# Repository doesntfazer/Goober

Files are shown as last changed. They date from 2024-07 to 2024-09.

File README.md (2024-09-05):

## Goober
The Goober is a Hummingbird-like layout.

There are several different versions of the Goober layout.
For firmware Check out the [Keyboard Dweebs Firmware Repositore](https://github.com/doesntfazer/Keyboard-Dweebs-Firmware-repository)

## Goober Original


This keyboard is hot-swap, runs on rp2040 zero.
## Goobertrax


This keyboard is hot-swap, runs on rp2040 zero, and has a PMW3360 sensor trackball
## Goobertrax-e


This keyboard is hot-swap, runs on rp2040 zero, and has a PMW3360 sensor trackball. Additionally, it has 2 Panasonic rotary encoders, and 3 extra keys for mouse buttons
## CHore


This keyboard runs on FAK firmware, and is powered by a CH552G microcontroller.
## Goober CHOC


Same as original but with slightly different layout, and it is Choc Spaced.
## Goober-wi
No image available yet. Split wireless Goober.

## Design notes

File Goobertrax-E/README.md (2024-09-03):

# Goobertrax-E
# Project is sponsored by PCBWay!
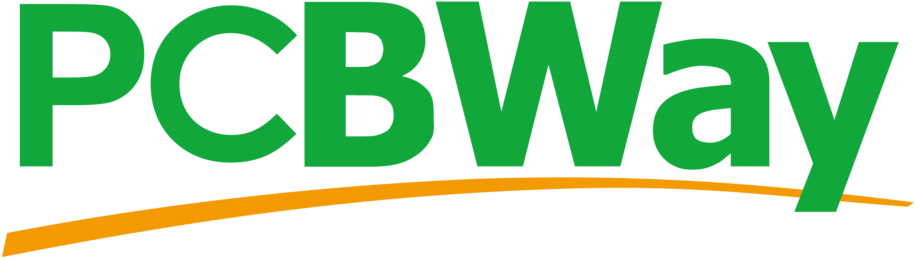
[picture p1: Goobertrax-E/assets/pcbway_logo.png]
PCBWay Logo


If you're not familiar with PCBWay, they're a fantastic company specializing in PCB prototyping and manufacturing. Whether you're a hobbyist or a professional, PCBWay offers high-quality PCB services at incredibly affordable prices. They offer a wide selection of colors and other options like full assembly!

I've been using PCBWay for my projects, and I can't recommend them enough. Their user-friendly interface makes it easy to upload your designs, and their fast turnaround times ensure you get your PCBs quickly, and you can finish your project on time. Plus, they offer a wide range of services, including PCB assembly, flexible PCBs, and even 3D printing and CNC!

Head on over to [PCBWay](https://pcbway.com/g/2afU7m) to get yourself a Goobertrax-E!

# About The Goobertrax-E
The Goobertrax-E is a 30 key hot swappable Hummingbird-like Keyboard using the RP2040 Zero for the MCU. Has a PMW3360 sensor Built into the PCB, 3 dedicated mouse keyb buttons, and supports 2 panisonic rotary encoders.

Keyboard is named the Goober because only a goober would use one. It is a very goofy keyboard. The thumbs keys are super "tucky" and it is awkward to figure out a layout. But once you get used to it, it just might become your favorite keyboard!

The keyboard runs on VIAL QMK firmware.
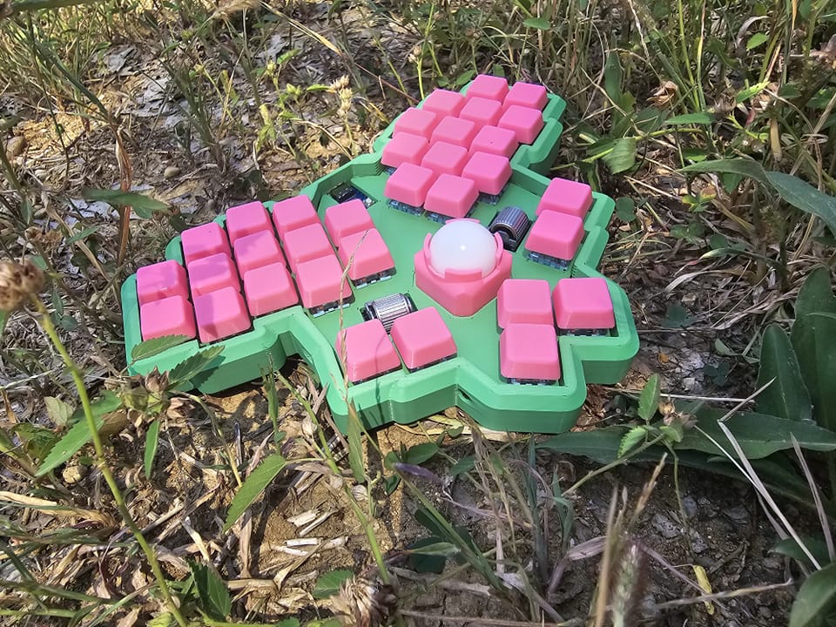
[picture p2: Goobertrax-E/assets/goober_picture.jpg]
Goober


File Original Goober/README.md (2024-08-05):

# Goober
# Project is sponsored by PCBWay!
PCBWay Logo

If you're not familiar with PCBWay, they're a fantastic company specializing in PCB prototyping and manufacturing. Whether you're a hobbyist or a professional, PCBWay offers high-quality PCB services at incredibly affordable prices. They offer a wide selection of colors and other options like full assembly!

I've been using PCBWay for my projects, and I can't recommend them enough. Their user-friendly interface makes it easy to upload your designs, and their fast turnaround times ensure you get your PCBs quickly, and you can finish your project on time. Plus, they offer a wide range of services, including PCB assembly, flexible PCBs, and even 3D printing and CNC!

Head on over to [PCBWay](https://pcbway.com/g/2afU7m) to get yourself a Goober!

# About The Goober
The goober is a 30 key hot swappable Hummingbird-like Keyboard using the RP2040 Zero for the MCU. This was designed to be caseless, although you are welcome to use the files in this repo to have a case 3D printed. Named the Goober because only a goober would use one. It is a very goofy keyboard. The thumbs keys are super "tucky" and it is awkward to figure out a layout. But once you get used to it, it just might become your favorite keyboard!

The keyboard runs on VIAL QMK firmware.
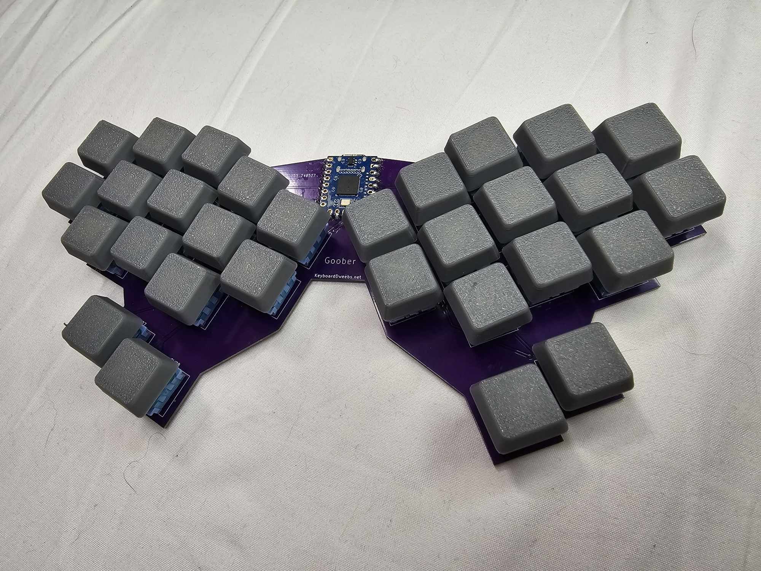
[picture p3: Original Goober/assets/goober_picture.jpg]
Goober

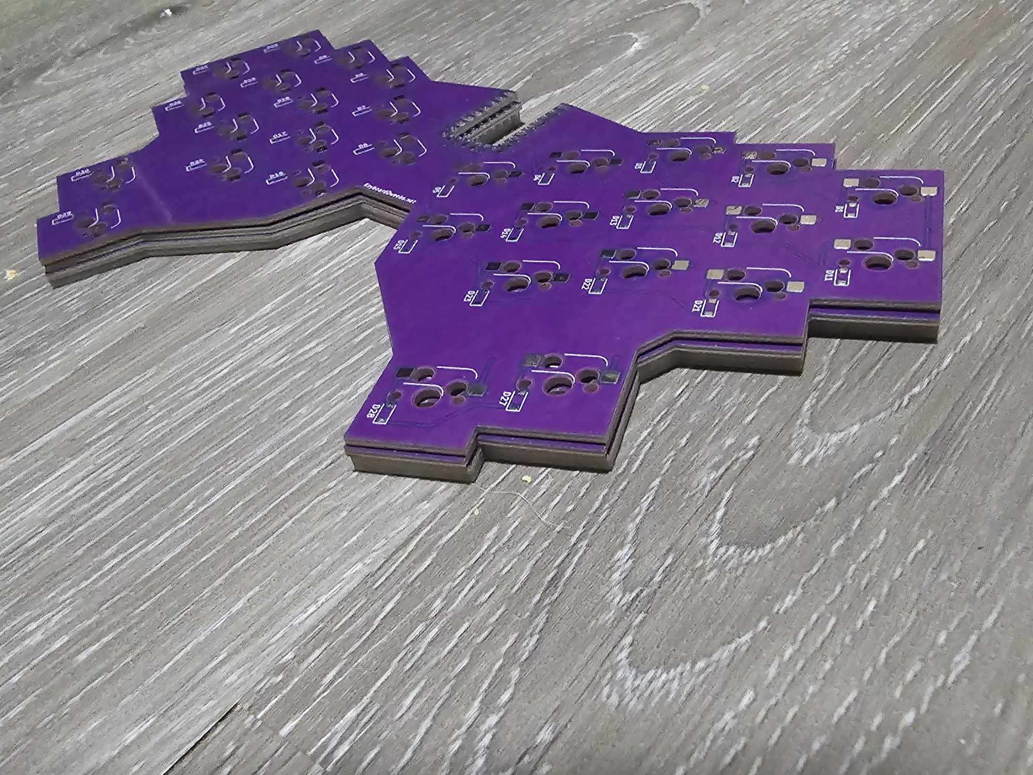
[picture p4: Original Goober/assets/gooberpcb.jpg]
Goober2


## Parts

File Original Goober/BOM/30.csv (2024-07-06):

Comment | Designator | Footprint
1 | U1 | rp2040-zero-tht-nocut-extendedpads
2 | SW30,SW29,SW28,SW27,SW26,SW25,SW24,SW23,SW22,SW21,SW20,SW19,SW18,SW17,SW16,SW15,SW14,SW13,SW12,SW11,SW10,SW9,SW8,SW7,SW6,SW5,SW4,SW3,SW2,SW1 | SW_Hotswap_Kailh_MX_1.00u
3 | D30,D29,D28,D27,D26,D25,D24,D23,D22,D21,D20,D19,D18,D17,D16,D15,D14,D13,D12,D11,D10,D9,D8,D7,D6,D5,D4,D3,D2,D1 | D_SOD-123

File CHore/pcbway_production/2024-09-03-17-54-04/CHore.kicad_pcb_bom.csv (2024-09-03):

Designator | Quantity | Value | Footprint | Package | MPN | Mount_Type
C1, C2, C3 | 3 | 100n | C_0805_2012Metric |  |  | smt
D1, D10, D11, D12, D13, D14, D15, D16, D17, D18, D19, D2, D20, D21, D22, D23, D24, D25, D26, D27, D28, D29, D3, D30, D31, D32, D33, D34, D35, D4, D5, D6, D7, D8, D9 | 35 | 1N4148W | D_SOD-123 |  |  | smt
J1, J3 | 2 | Conn_01x02_Pin | PinHeader_1x02_P2.54mm_Vertical |  |  | tht
J2 | 1 | USB_C_Receptacle_USB2.0 | USB_C_Receptacle_HRO_TYPE-C-31-M-12 |  |  | smt
R1 | 1 | 330R | R_0805_2012Metric |  |  | smt
R2, R3 | 2 | 5.1k | R_0805_2012Metric |  |  | smt
R4 | 1 | 10K | R_0805_2012Metric |  |  | smt
SW1, SW10, SW11, SW12, SW13, SW14, SW15, SW16, SW17, SW18, SW19, SW2, SW20, SW21, SW22, SW23, SW24, SW25, SW26, SW27, SW28, SW29, SW3, SW30, SW4, SW5, SW6, SW7, SW8, SW9 | 30 | SW_PUSH | SW_Hotswap_Kailh_MX_1.00u |  |  | smt
U1 | 1 | CH552G | STC_SOP-16_3.9x9.9mm_P1.27mm |  |  | smt

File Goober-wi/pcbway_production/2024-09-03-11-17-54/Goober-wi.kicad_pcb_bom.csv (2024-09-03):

Designator | Quantity | Value | Footprint | Package | MPN | Mount_Type
J1 | 1 | Conn_01x02 | PinHeader_1x02_P2.54mm_Vertical |  |  | tht
S1, S2 | 2 | PTS526_SM08_SMTR2_LFS | SW_PTS526_SM08_SMTR2_LFS | None |  | smt
SW1, SW10, SW11, SW12, SW13, SW14, SW15, SW2, SW3, SW4, SW5, SW6, SW7, SW8, SW9 | 15 | SW_PUSH | SW_Kailh_Choc_V1V2_1.00u - Reversable |  |  | tht
SW16 | 1 | SW_SPDT | switch-MSK-12C02-smd |  |  | smt
U1 | 1 | nice_nano | nice_nano |  |  | tht

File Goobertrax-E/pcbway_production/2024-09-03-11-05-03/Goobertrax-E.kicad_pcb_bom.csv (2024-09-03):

Designator | Quantity | Value | Footprint | Package | MPN | Mount_Type
C1001, C1003 | 2 | 1uF | C_0603_1608Metric |  |  | smt
C1002 | 1 | 4.7uF | C_0603_1608Metric |  |  | smt
D1, D10, D11, D12, D13, D14, D15, D16, D17, D18, D19, D2, D20, D21, D22, D23, D24, D25, D26, D27, D28, D29, D3, D30, D31, D32, D33, D34, D35, D4, D5, D6, D7, D8, D9 | 35 | 1N4148W | D_SOD-123 |  |  | smt
E1, E2 | 2 | ~ | EVQWGD001 |  |  | tht
IC1001 | 1 | AP7335-WG-7 | SOT-23-5_HandSoldering |  | AP7331-WG-7 | smt
R1, R1002, R1004, R2, R3, R4, R5 | 7 | 10k | R_0603_1608Metric |  |  | smt
R1001 | 1 | 39 | R_0603_1608Metric |  |  | smt
R1003 | 1 | 15k | R_0603_1608Metric |  |  | smt
SW1, SW10, SW11, SW12, SW13, SW14, SW15, SW16, SW17, SW18, SW19, SW2, SW20, SW21, SW22, SW23, SW24, SW25, SW26, SW27, SW28, SW29, SW3, SW30, SW31, SW32, SW33, SW4, SW5, SW6, SW7, SW8, SW9 | 33 | SW_PUSH | SW_Hotswap_Kailh_MX_1.00u |  |  | smt
U1 | 1 | rp2040-zero | rp2040-zero-tht-nocut-largerpads |  |  | tht
U1001 | 1 | PMW3360DM-T2QU | DIP-16_W10.16mm |  |  | tht

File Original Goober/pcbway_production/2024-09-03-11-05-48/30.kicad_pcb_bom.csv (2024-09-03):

Designator | Quantity | Value | Footprint | Package | MPN | Mount_Type
D1, D10, D11, D12, D13, D14, D15, D16, D17, D18, D19, D2, D20, D21, D22, D23, D24, D25, D26, D27, D28, D29, D3, D30, D4, D5, D6, D7, D8, D9 | 30 | 1N4148W | D_SOD-123 |  |  | smt
SW1, SW10, SW11, SW12, SW13, SW14, SW15, SW16, SW17, SW18, SW19, SW2, SW20, SW21, SW22, SW23, SW24, SW25, SW26, SW27, SW28, SW29, SW3, SW30, SW4, SW5, SW6, SW7, SW8, SW9 | 30 | SW_Push | SW_Hotswap_Kailh_MX_1.00u |  |  | smt
U1 | 1 | rp2040-zero | rp2040-zero-tht-nocut-extendedpads |  |  | tht

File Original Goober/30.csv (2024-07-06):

Id | Designator | Footprint | Quantity | Designation | Supplier and ref
1 | U1 | rp2040-zero-tht-nocut-extendedpads | 1 | rp2040-zero
2 | SW30,SW29,SW28,SW27,SW26,SW25,SW24,SW23,SW22,SW21,SW20,SW19,SW18,SW17,SW16,SW15,SW14,SW13,SW12,SW11,SW10,SW9,SW8,SW7,SW6,SW5,SW4,SW3,SW2,SW1 | SW_Hotswap_Kailh_MX_1.00u | 30 | SW_Push
3 | D30,D29,D28,D27,D26,D25,D24,D23,D22,D21,D20,D19,D18,D17,D16,D15,D14,D13,D12,D11,D10,D9,D8,D7,D6,D5,D4,D3,D2,D1 | D_SOD-123 | 30 | 1N4148W

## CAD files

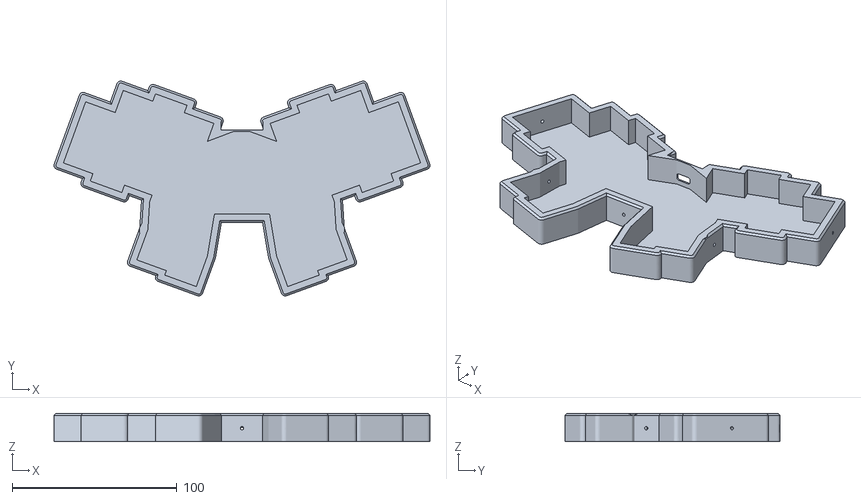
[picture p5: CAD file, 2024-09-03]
CHore/Case/Case.stl
227.9 x 130.3 x 17.0

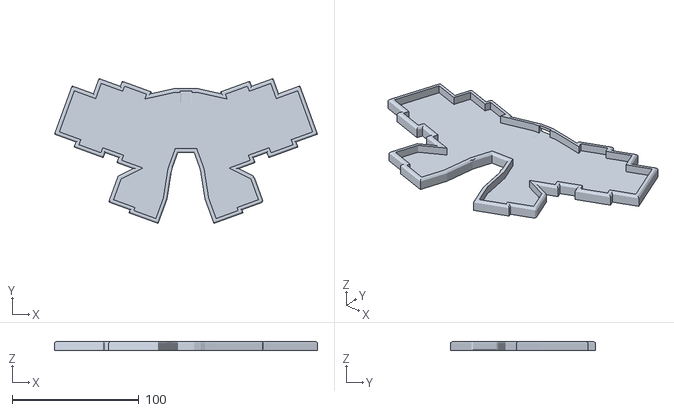
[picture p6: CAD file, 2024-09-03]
goober-CHOC/dxf/case.stl
207.7 x 114.4 x 7.00

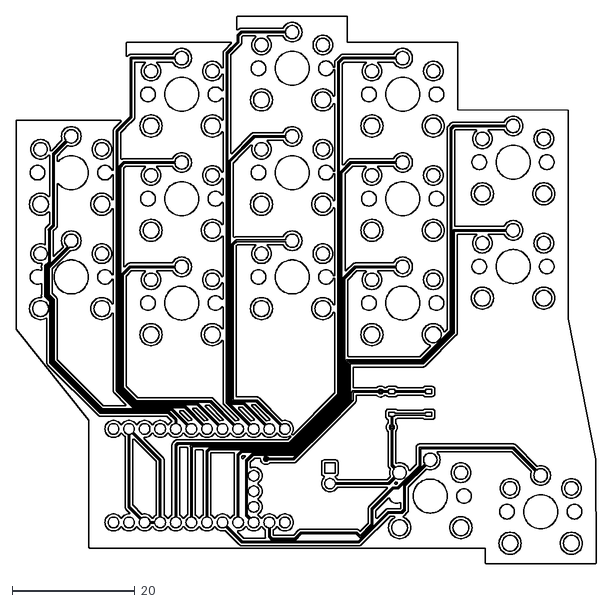
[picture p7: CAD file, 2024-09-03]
Goober-wi/DXF/foldiboiwi-B_Cu.dxf
94.5 x 89.2

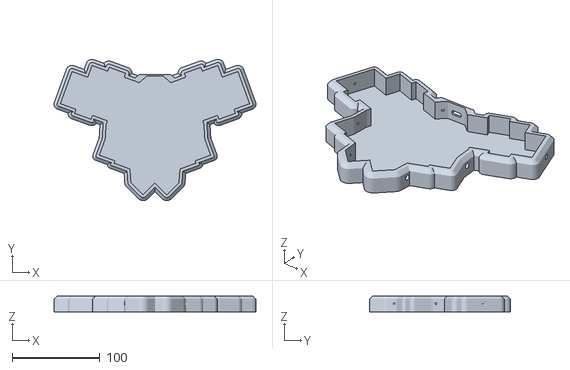
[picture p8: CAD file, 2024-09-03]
Goobertrax-E/3d Models - Case files/Case.stl
230.6 x 161.3 x 18.0

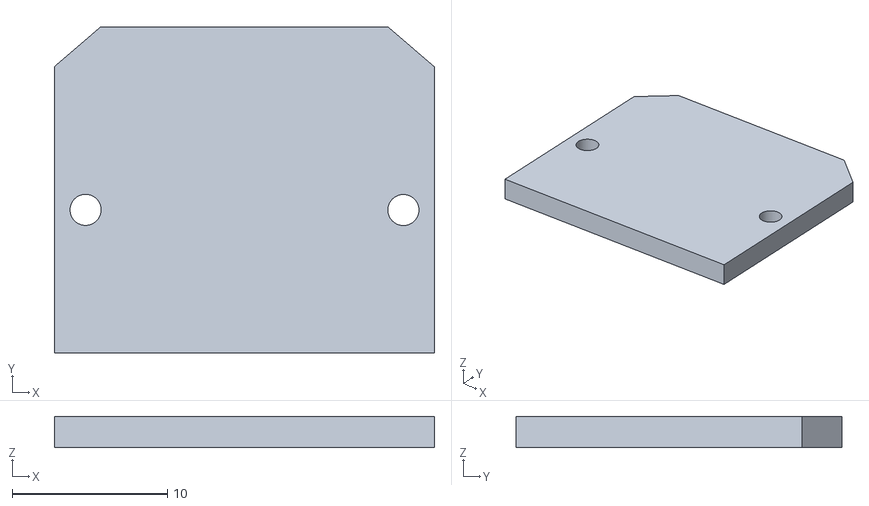
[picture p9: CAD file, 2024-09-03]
Goobertrax/3d Models - Case files/Cover.stl
24.5 x 21.0 x 2.00

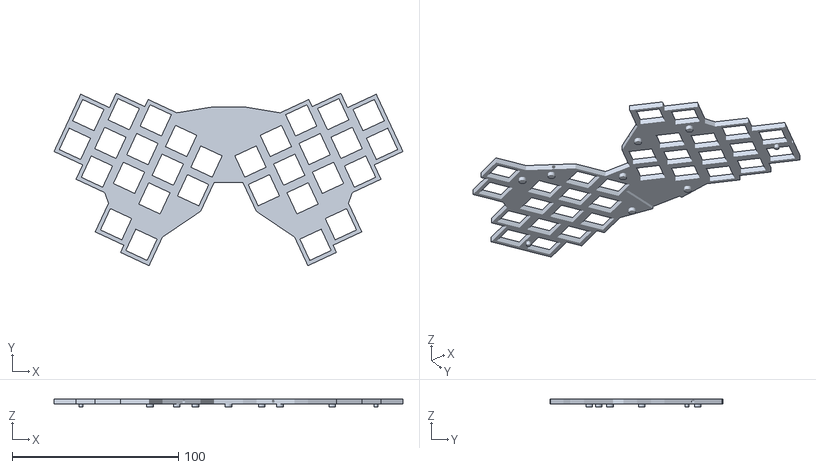
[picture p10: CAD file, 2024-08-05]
Original Goober/Case Files/plate-goober.stl
209.9 x 103.7 x 5.00

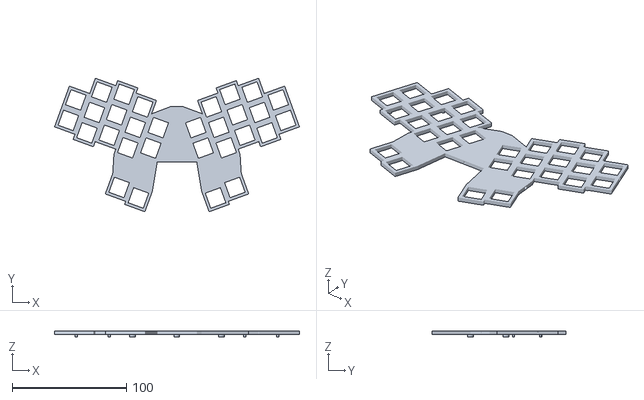
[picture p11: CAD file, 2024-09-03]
CHore/Case/Plate.stl
214.7 x 117.1 x 5.00

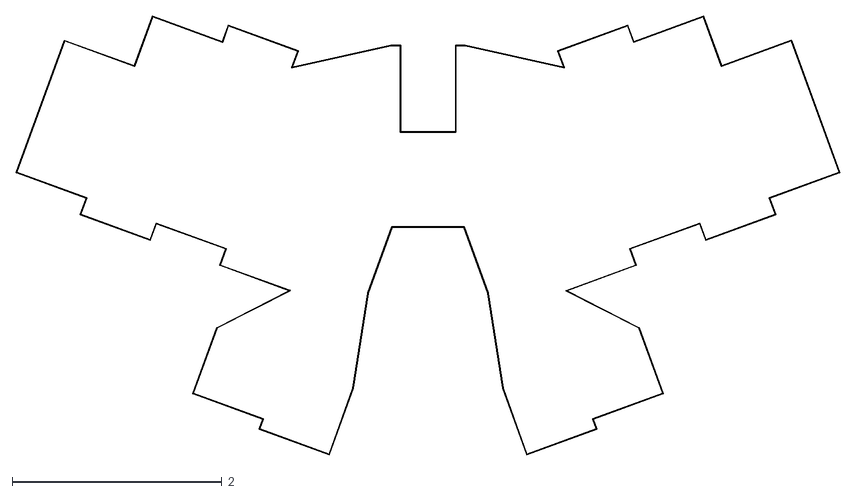
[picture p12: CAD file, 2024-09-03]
goober-CHOC/dxf/goober-wi-Edge_Cuts.dxf
7.85 x 4.18

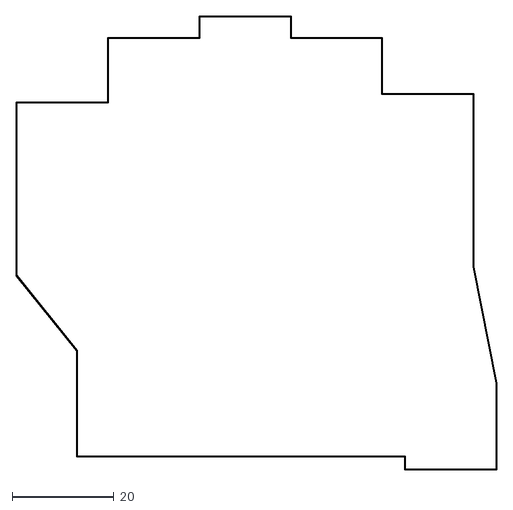
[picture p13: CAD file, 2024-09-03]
Goober-wi/DXF/foldiboiwi-Edge_Cuts.dxf
94.6 x 89.3

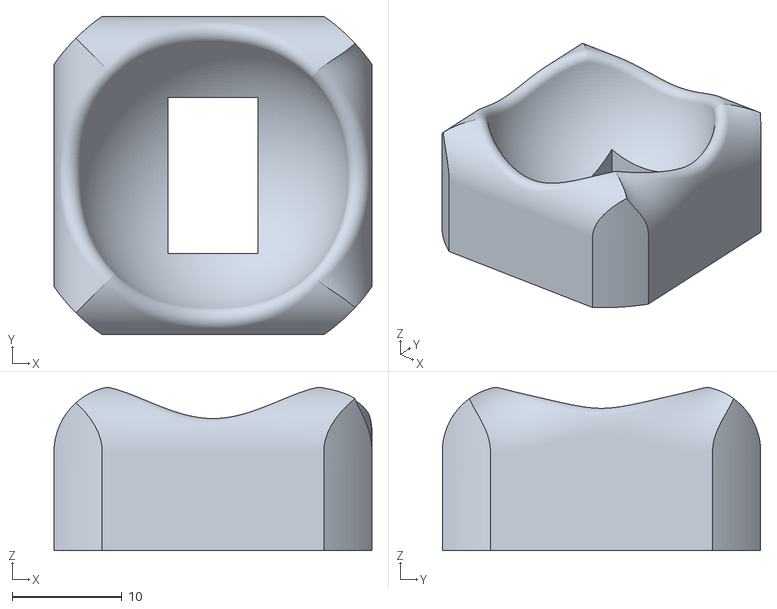
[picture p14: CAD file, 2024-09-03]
Goobertrax-E/3d Models - Case files/trackball holder.stl
29.0 x 29.0 x 14.9

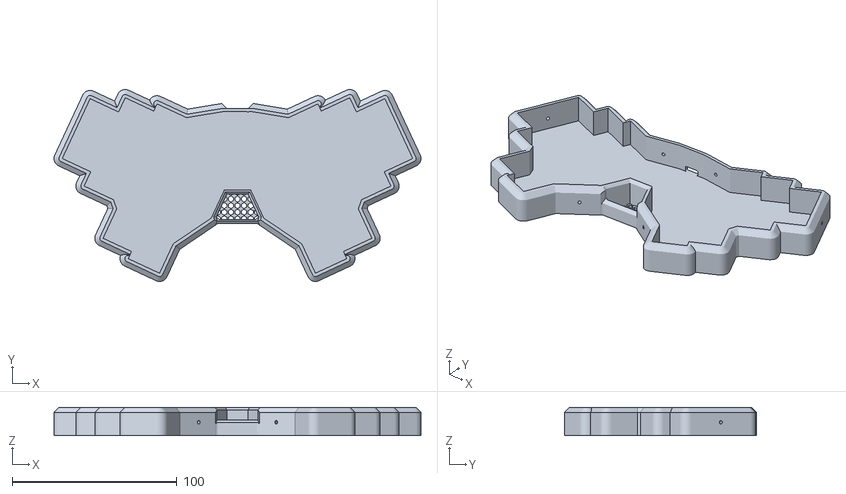
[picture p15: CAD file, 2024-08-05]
Original Goober/Case Files/case-Goober.stl
222.5 x 116.4 x 17.1

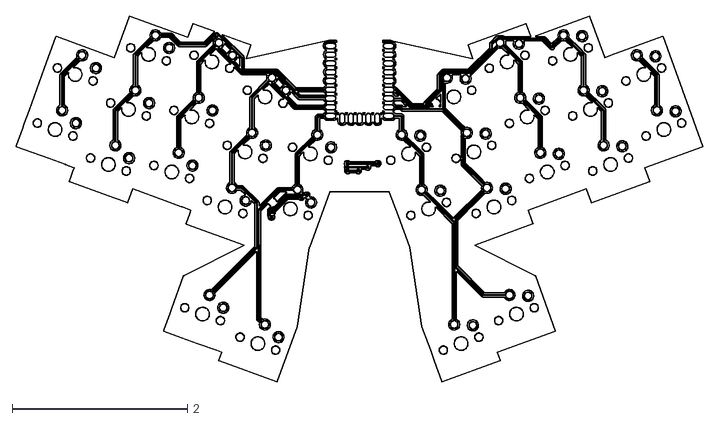
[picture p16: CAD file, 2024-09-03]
goober-CHOC/dxf/goober-wi-F_Cu.dxf
7.84 x 4.17

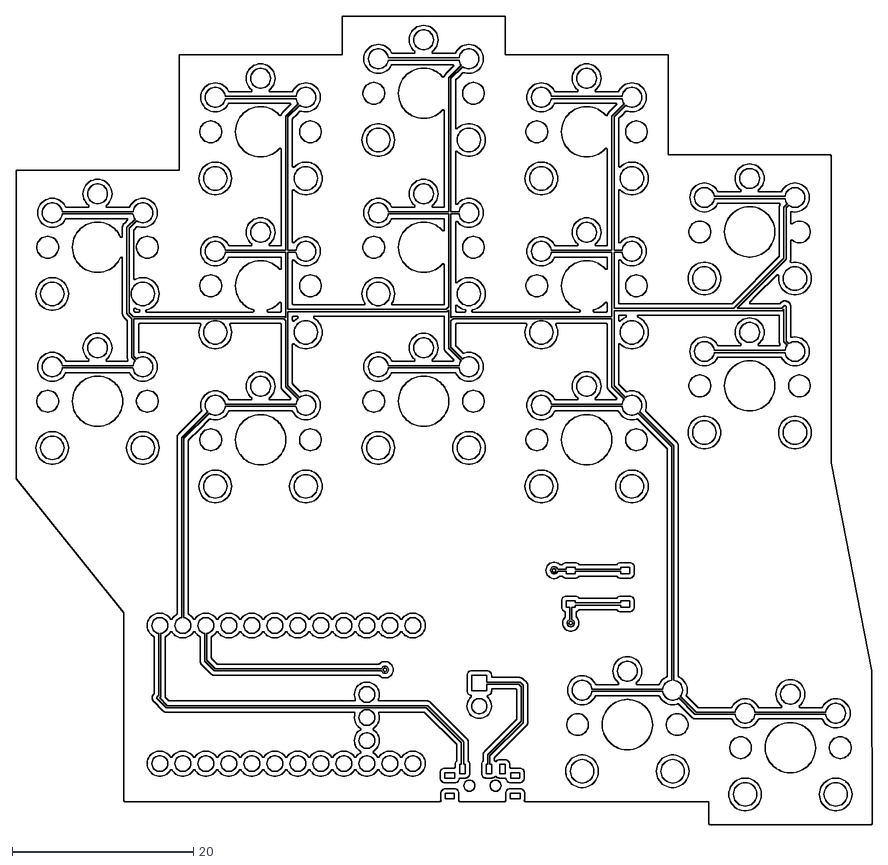
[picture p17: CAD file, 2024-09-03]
Goober-wi/DXF/foldiboiwi-F_Cu.dxf
94.5 x 89.2

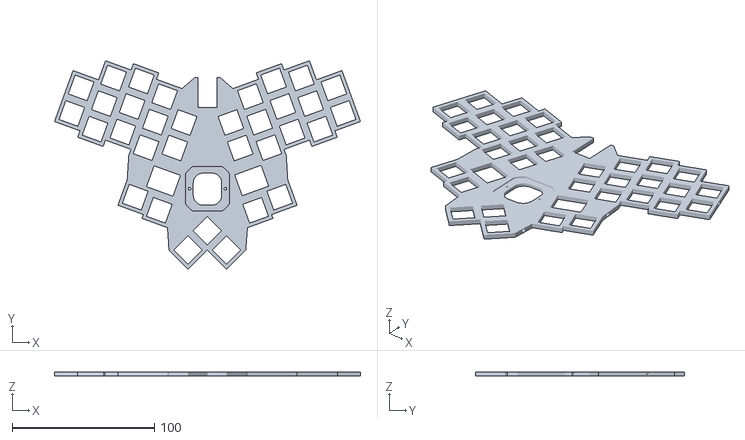
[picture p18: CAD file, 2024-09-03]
Goobertrax-E/3d Models - Case files/Plate.stl
214.8 x 146.4 x 3.00

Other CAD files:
Goobertrax/3d Models - Case files/Trackball Holder - Click-in.stl
goober-CHOC/dxf/goober-wi-B_Cu.dxf
Goobertrax-E/3d Models - Case files/Trackball Holder - Click-in.stl
Goober-wi/DXF/foldiboiwi-B_Mask.dxf
Goober-wi/DXF/foldiboiwi-B_Paste.dxf
Goober-wi/DXF/foldiboiwi-B_Silkscreen.dxf
Goober-wi/DXF/foldiboiwi-F_Mask.dxf
Goober-wi/DXF/foldiboiwi-F_Paste.dxf
Goober-wi/DXF/foldiboiwi-F_Silkscreen.dxf
Goobertrax/3d Models - Case files/Case.stl
Goobertrax/3d Models - Case files/Plate.stl
goober-CHOC/dxf/goober-wi-B_Mask.dxf
goober-CHOC/dxf/goober-wi-B_Paste.dxf
goober-CHOC/dxf/goober-wi-B_Silkscreen.dxf
goober-CHOC/dxf/goober-wi-F_Mask.dxf
goober-CHOC/dxf/goober-wi-F_Paste.dxf
goober-CHOC/dxf/goober-wi-F_Silkscreen.dxf

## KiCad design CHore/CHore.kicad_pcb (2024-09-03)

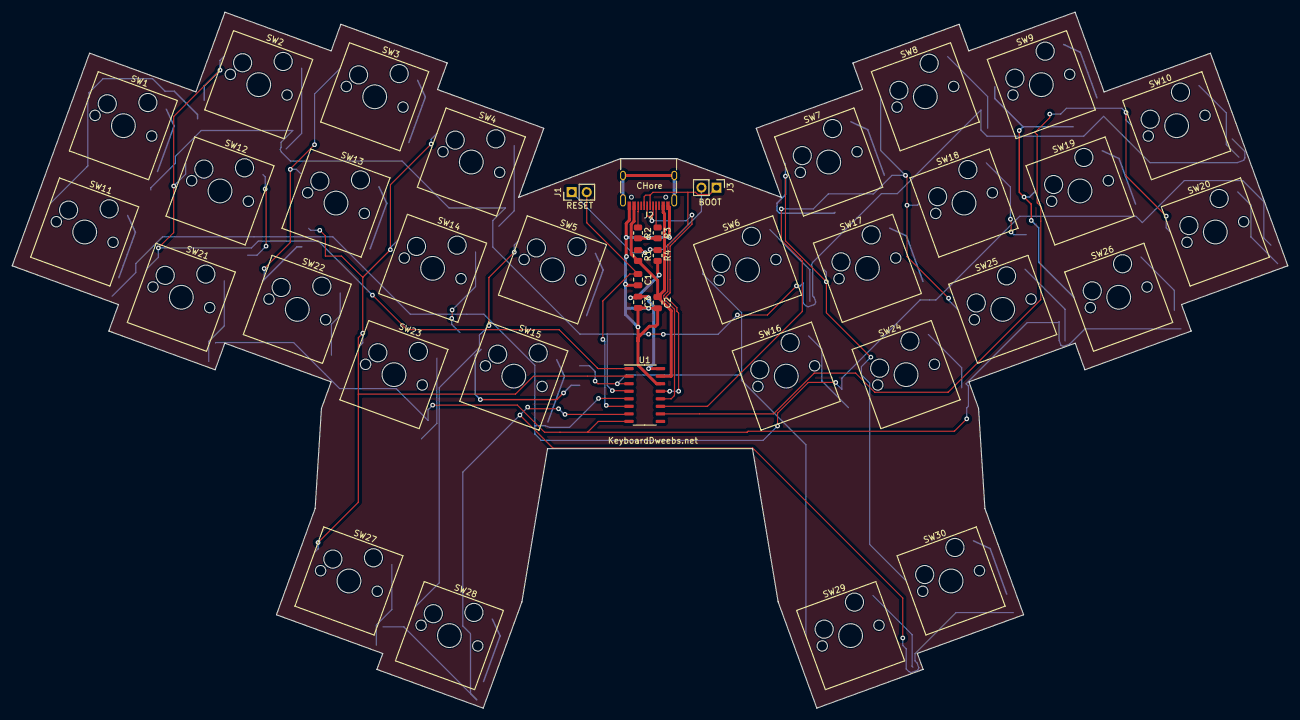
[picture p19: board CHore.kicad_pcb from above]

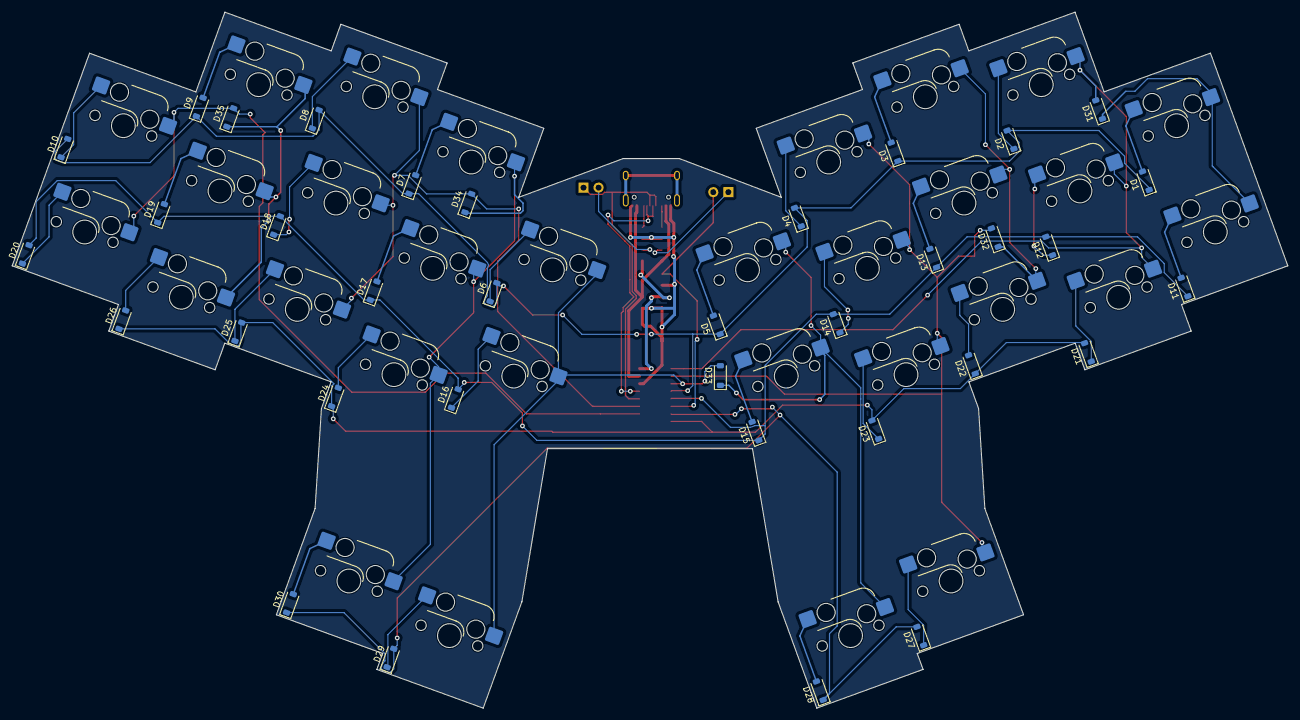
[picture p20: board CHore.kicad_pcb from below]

Board: 2 copper layers, 214.8 x 117.2 mm, 76 parts (35 on the bottom side), 54 nets.

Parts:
C1, C2, C3: 100n; C_0805_2012Metric
D1, D2, D3, D4, D5, D6, D7, D8, D9, D10, D11, D12, D13, D14, D15, D16, D17, D18, D19, D20, D21, D22, D23, D24, D25, D26, D27, D28, D29, D30, D31, D32, D33, D34, D35: 1N4148W; D_SOD-123
J1, J3: Conn_01x02_Pin; PinHeader_1x02_P2.54mm_Vertical
J2: USB_C_Receptacle_USB2.0; USB_C_Receptacle_HRO_TYPE-C-31-M-12
R1: 330R; R_0805_2012Metric
R2, R3: 5.1k; R_0805_2012Metric
R4: 10K; R_0805_2012Metric
SW1, SW2, SW3, SW4, SW5, SW6, SW7, SW8, SW9, SW10, SW11, SW12, SW13, SW14, SW15, SW16, SW17, SW18, SW19, SW20, SW21, SW22, SW23, SW24, SW25, SW26, SW27, SW28, SW29, SW30: SW_PUSH; SW_Hotswap_Kailh_MX_1.00u
U1: CH552G; STC_SOP-16_3.9x9.9mm_P1.27mm

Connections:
/3V3: C3.1, R4.2, U1.16 (V33)
/5v: C2.1, J2.A4 (VBUS), J2.A9 (VBUS), J2.B4 (VBUS), J2.B9 (VBUS), R1.2, U1.15 (VCC/VDD)
/COL0: D31.2 (A), SW2.1, SW12.1, SW21.1, U1.1 (P3.2/TXD1_/INT0/VBUS1/AIN3)
/COL1: D32.2 (A), SW4.1, SW14.1, SW23.1, SW27.1, U1.2 (P1.4/T2_/CAP1_/SCS/TIN2/UCC1/AIN1)
/COL2: D33.2 (A), SW6.1, SW16.1, SW29.1, U1.3 (P1.5/MOSI/PWM1/TIN3/UCC2/AIN2)
/COL3: D34.2 (A), SW8.1, SW18.1, SW25.1, U1.11 (P3.4/PWM2/RXD1_/T0)
/COL4: D35.2 (A), SW10.1, SW20.1, U1.10 (P3.3/INT1)
/DATA+: J2.A6 (D+), J2.B6 (D+), J3.1, U1.12 (P3.6/UDP)
/DATA-: J2.A7 (D-), J2.B7 (D-), U1.13 (P3.7/UDM)
/GND: C1.2, C2.2, C3.2, J2.A1 (GND), J2.A12 (GND), J2.B1 (GND), J2.B12 (GND), R2.2, R3.2, U1.14 (GND/VSS)
/RESET: C1.1, J1.2, U1.6 (RST/T2EX_/CAP2_)
/ROW0: D1.1 (K), D2.2 (A), D3.1 (K), D4.2 (A), D5.1 (K), D6.2 (A), D7.1 (K), D8.2 (A), D9.1 (K), D10.2 (A), U1.4 (P1.6/MISO/RXD1/TIN4)
/ROW1: D11.1 (K), D12.2 (A), D13.1 (K), D14.2 (A), D15.1 (K), D16.2 (A), D17.1 (K), D18.2 (A), D19.1 (K), D20.2 (A), U1.5 (P1.7/SCK/TXD1/TIN5)
/ROW2: D21.2 (A), D22.1 (K), D23.2 (A), D24.1 (K), D25.2 (A), D26.1 (K), U1.8 (P3.0/PWM1_/RXD)
/ROW3: D27.2 (A), D28.1 (K), D29.2 (A), D30.1 (K), U1.7 (P3.1/PWM2_/TXD)
unnamed: D1.2 (A), SW1.2
unnamed: D2.1 (K), SW2.2
unnamed: D3.2 (A), SW3.2
unnamed: D4.1 (K), SW4.2
unnamed: D5.2 (A), SW5.2
unnamed: D6.1 (K), SW6.2
unnamed: D7.2 (A), SW7.2
unnamed: D8.1 (K), SW8.2
unnamed: D9.2 (A), SW9.2
unnamed: D10.1 (K), SW10.2
unnamed: D11.2 (A), SW11.2
unnamed: D12.1 (K), SW12.2
unnamed: D13.2 (A), SW13.2
unnamed: D14.1 (K), SW14.2
unnamed: D15.2 (A), SW15.2
unnamed: D16.1 (K), SW16.2
unnamed: D17.2 (A), SW17.2
unnamed: D18.1 (K), SW18.2
unnamed: D19.2 (A), SW19.2
unnamed: D20.1 (K), SW20.2
unnamed: D21.1 (K), SW21.2
unnamed: D22.2 (A), SW22.2
unnamed: D23.1 (K), SW23.2
unnamed: D24.2 (A), SW24.2
unnamed: D25.1 (K), SW25.2
unnamed: D26.2 (A), SW26.2
unnamed: D27.1 (K), SW27.2
unnamed: D28.2 (A), SW28.2
unnamed: D29.1 (K), SW29.2
unnamed: D30.2 (A), SW30.2
unnamed: D31.1 (K), SW1.1, SW11.1
unnamed: D32.1 (K), SW3.1, SW13.1, SW22.1
unnamed: D33.1 (K), SW5.1, SW15.1, SW28.1
unnamed: D34.1 (K), SW7.1, SW17.1, SW24.1, SW30.1
unnamed: D35.1 (K), SW9.1, SW19.1, SW26.1
unnamed: J1.1, R1.1
unnamed: J2.A5 (CC1), R3.1
unnamed: J2.B5 (CC2), R2.1
unnamed: J3.2, R4.1

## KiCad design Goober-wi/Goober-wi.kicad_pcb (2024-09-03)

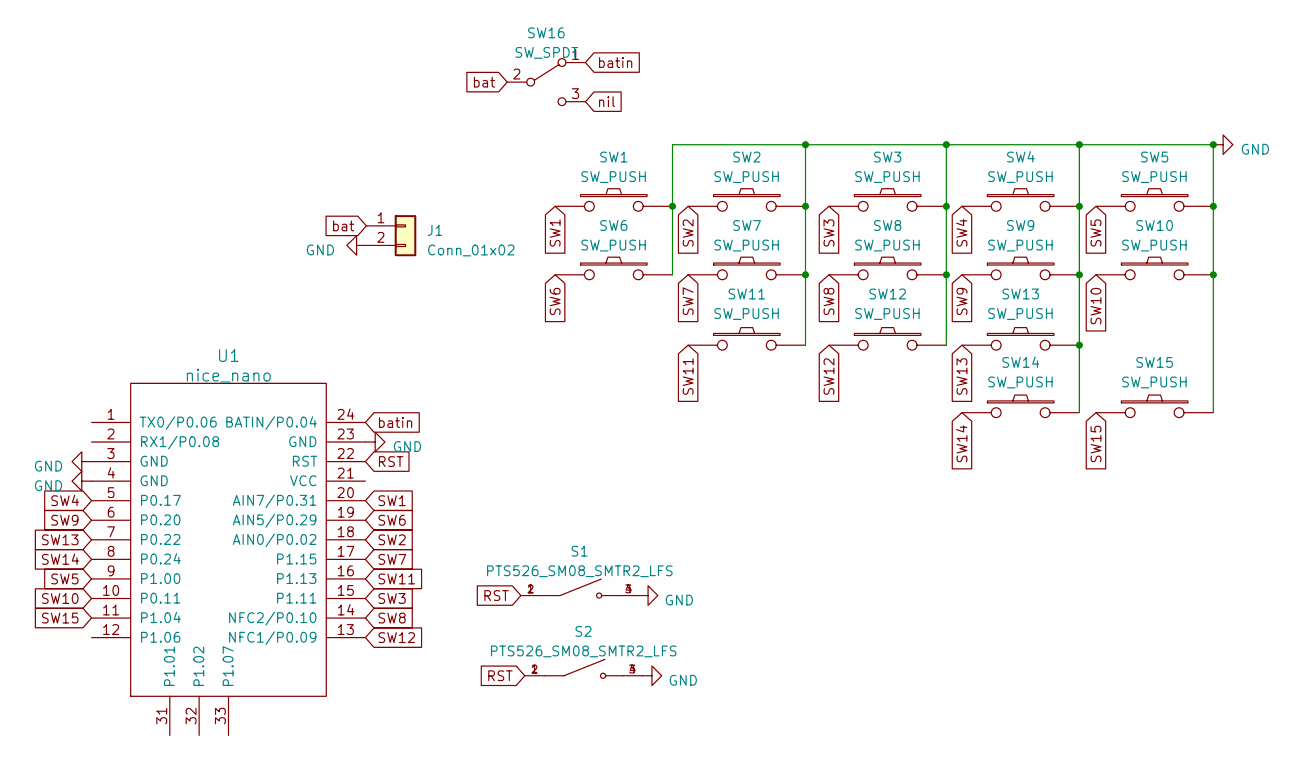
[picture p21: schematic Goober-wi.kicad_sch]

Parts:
J1: Conn_01x02; PinHeader_1x02_P2.54mm_Vertical
S1, S2: PTS526_SM08_SMTR2_LFS; SW_PTS526_SM08_SMTR2_LFS; PARTREV 20 mar 19
SW1, SW2, SW3, SW4, SW5, SW6, SW7, SW8, SW9, SW10, SW11, SW12, SW13, SW14, SW15: SW_PUSH; SW_Kailh_Choc_V1V2_1.00u - Reversable
SW16: SW_SPDT; switch-MSK-12C02-smd
U1: nice_nano

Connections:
GND: J1.2, S1.3, S1.4, S2.3, S2.4, SW1.2, SW2.2, SW3.2, SW4.2, SW5.2, SW6.2, SW7.2, SW8.2, SW9.2, SW10.2, SW11.2, SW12.2, SW13.2, SW14.2, SW15.2, U1.3 (GND), U1.4 (GND), U1.23 (GND)
RST: S1.1, S1.2, S2.1, S2.2, U1.22 (RST)
SW1: SW1.1, U1.20 (AIN7/P0.31)
SW2: SW2.1, U1.18 (AIN0/P0.02)
SW3: SW3.1, U1.15 (P1.11)
SW4: SW4.1, U1.5 (P0.17)
SW5: SW5.1, U1.9 (P1.00)
SW6: SW6.1, U1.19 (AIN5/P0.29)
SW7: SW7.1, U1.17 (P1.15)
SW8: SW8.1, U1.14 (NFC2/P0.10)
SW9: SW9.1, U1.6 (P0.20)
SW10: SW10.1, U1.10 (P0.11)
SW11: SW11.1, U1.16 (P1.13)
SW12: SW12.1, U1.13 (NFC1/P0.09)
SW13: SW13.1, U1.7 (P0.22)
SW14: SW14.1, U1.8 (P0.24)
SW15: SW15.1, U1.11 (P1.04)
bat: J1.1, SW16.2 (B)
batin: SW16.1 (A), U1.24 (BATIN/P0.04)
nil: SW16.3 (C)

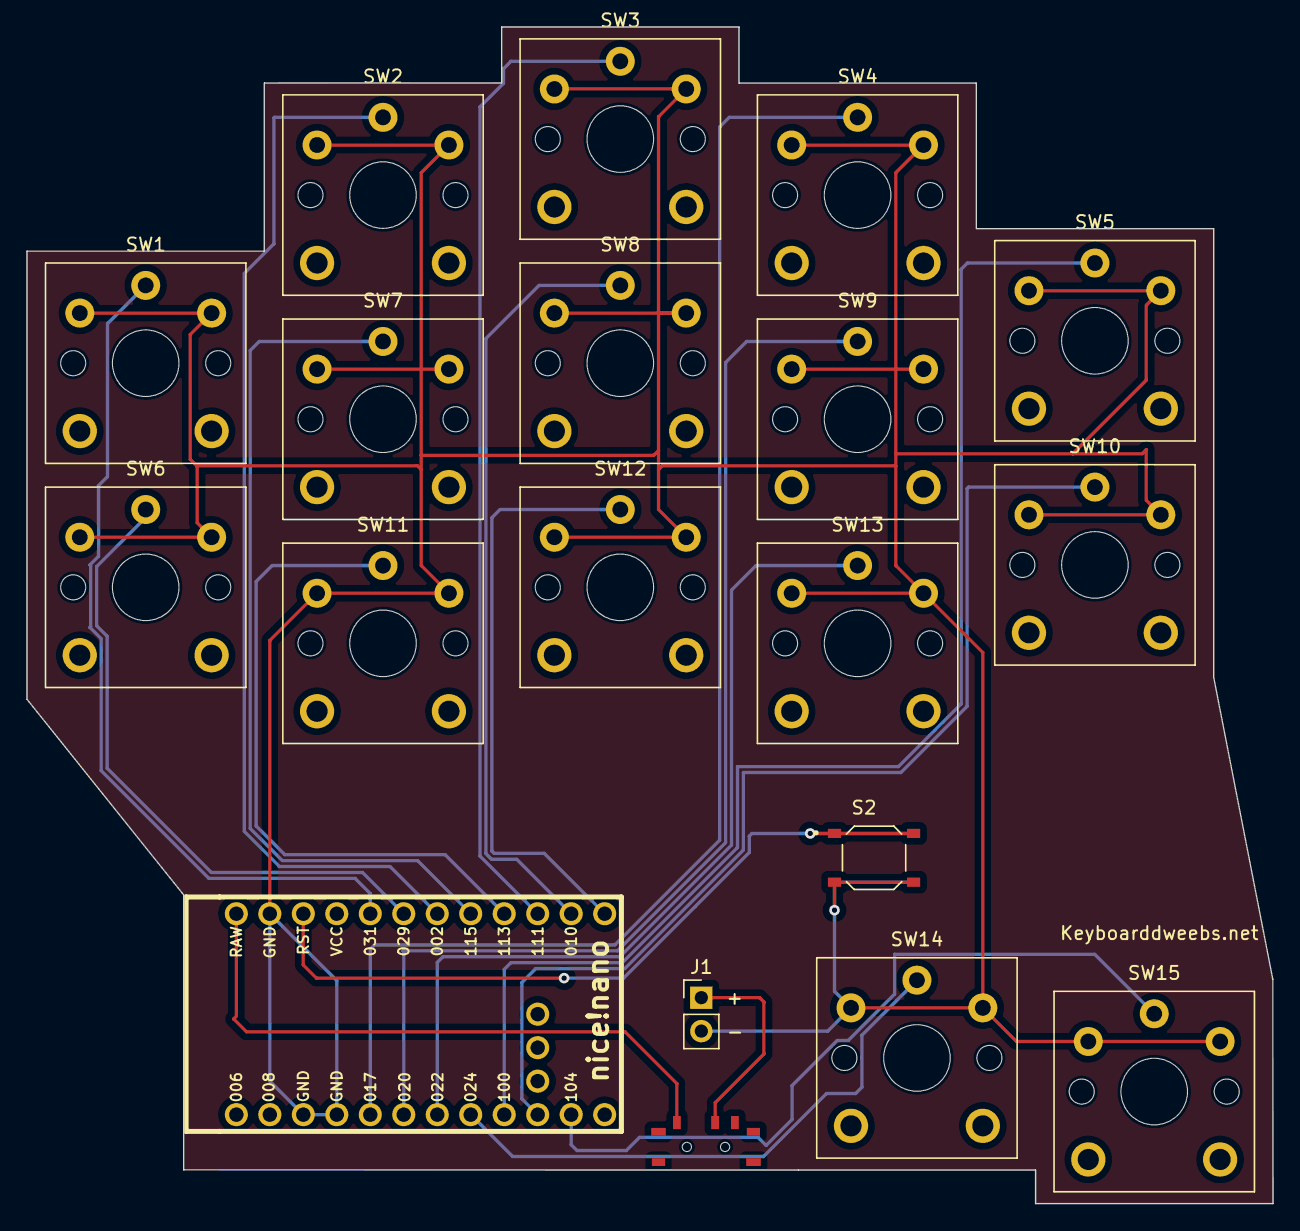
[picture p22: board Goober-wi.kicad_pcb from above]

Board: 2 copper layers, 94.5 x 89.2 mm, 20 parts (1 on the bottom side), 19 nets.

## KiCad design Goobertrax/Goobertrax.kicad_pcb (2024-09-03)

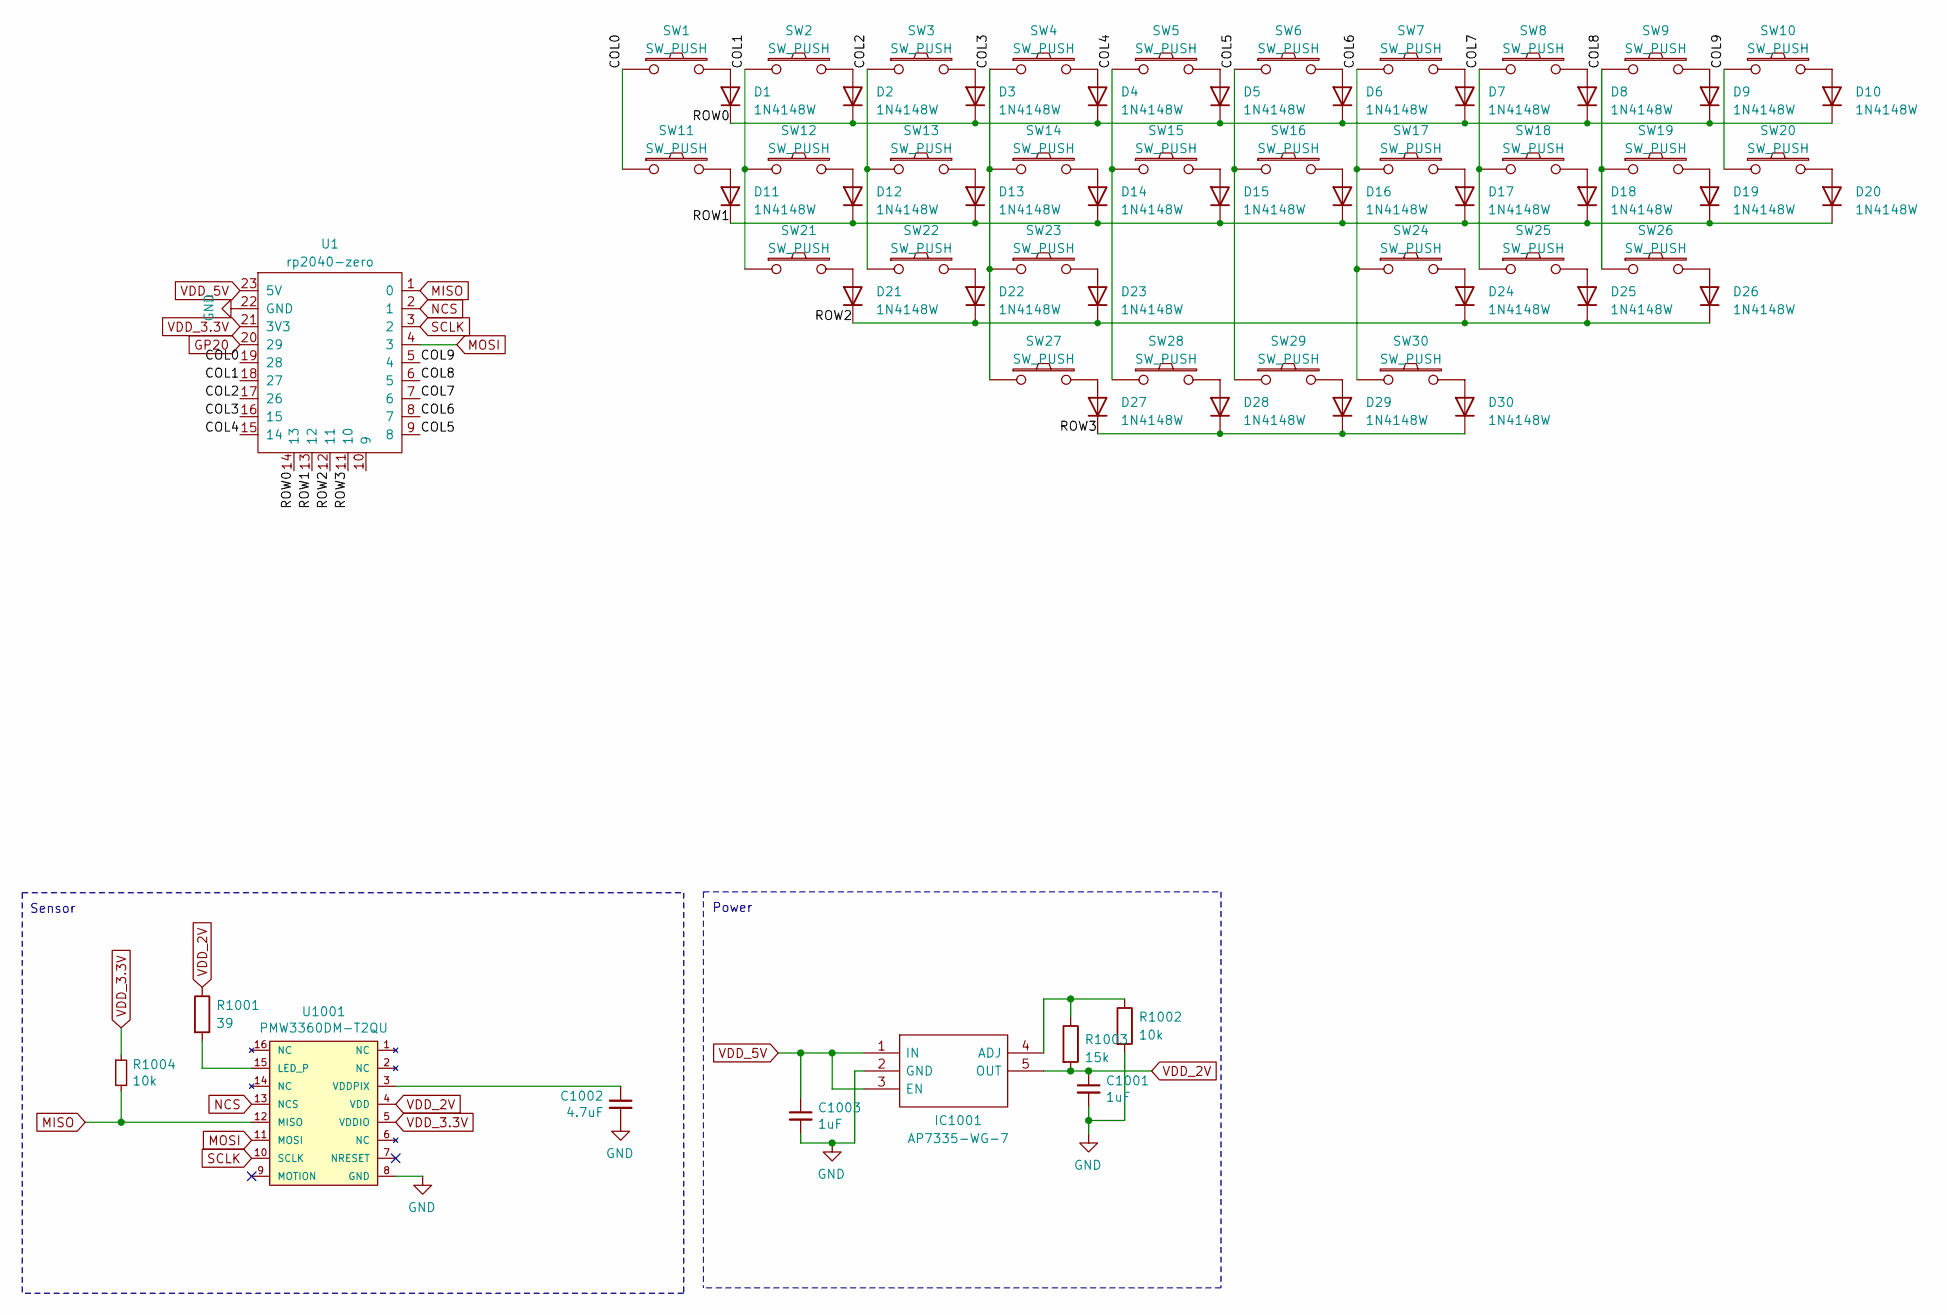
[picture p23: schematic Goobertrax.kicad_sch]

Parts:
C1001, C1003: 1uF; C_0603_1608Metric; LCSC C15849
C1002: 4.7uF; C_0603_1608Metric; LCSC C19666
D1, D2, D3, D4, D5, D6, D7, D8, D9, D10, D11, D12, D13, D14, D15, D16, D17, D18, D19, D20, D21, D22, D23, D24, D25, D26, D27, D28, D29, D30: 1N4148W; D_SOD-123
IC1001: AP7335-WG-7; SOT-23-5_HandSoldering; Manufacturer_Part_Number AP7331-WG-7; Mouser Part Number 621-AP7331-WG-7
R1001: 39; R_0603_1608Metric; LCSC C23154
R1002, R1004: 10k; R_0603_1608Metric; LCSC C25804
R1003: 15k; R_0603_1608Metric; LCSC C22809
SW1, SW2, SW3, SW4, SW5, SW6, SW7, SW8, SW9, SW10, SW11, SW12, SW13, SW14, SW15, SW16, SW17, SW18, SW19, SW20, SW21, SW22, SW23, SW24, SW25, SW26, SW27, SW28, SW29, SW30: SW_PUSH; SW_Hotswap_Kailh_MX_1.00u
U1: rp2040-zero; rp2040-zero-tht-nocut-largerpads
U1001: PMW3360DM-T2QU; DIP-16_W10.16mm

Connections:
/COL0: SW1.1, SW11.1, U1.19 (28)
/COL1: SW2.1, SW12.1, SW21.1, U1.18 (27)
/COL2: SW3.1, SW13.1, SW22.1, U1.17 (26)
/COL3: SW4.1, SW14.1, SW23.1, SW27.1, U1.16 (15)
/COL4: SW5.1, SW15.1, SW28.1, U1.15 (14)
/COL5: SW6.1, SW16.1, SW29.1, U1.9 (8)
/COL6: SW7.1, SW17.1, SW24.1, SW30.1, U1.8 (7)
/COL7: SW8.1, SW18.1, SW25.1, U1.7 (6)
/COL8: SW9.1, SW19.1, SW26.1, U1.6 (5)
/COL9: SW10.1, SW20.1, U1.5 (4)
/ROW0: D1.1 (K), D2.1 (K), D3.1 (K), D4.1 (K), D5.1 (K), D6.1 (K), D7.1 (K), D8.1 (K), D9.1 (K), D10.1 (K), U1.14 (13)
/ROW1: D11.1 (K), D12.1 (K), D13.1 (K), D14.1 (K), D15.1 (K), D16.1 (K), D17.1 (K), D18.1 (K), D19.1 (K), D20.1 (K), U1.13 (12)
/ROW2: D21.1 (K), D22.1 (K), D23.1 (K), D24.1 (K), D25.1 (K), D26.1 (K), U1.12 (11)
/ROW3: D27.1 (K), D28.1 (K), D29.1 (K), D30.1 (K), U1.11 (10)
GND: C1001.2, C1002.2, C1003.2, IC1001.2 (GND), R1002.2, U1.22 (GND), U1001.8 (GND)
MISO: R1004.2, U1.1 (0), U1001.12 (MISO)
MOSI: U1.4 (3), U1001.11 (MOSI)
NCS: U1.2 (1), U1001.13 (NCS)
unnamed: D1.2 (A), SW1.2
unnamed: D2.2 (A), SW2.2
unnamed: D3.2 (A), SW3.2
unnamed: D4.2 (A), SW4.2
unnamed: D5.2 (A), SW5.2
unnamed: D6.2 (A), SW6.2
unnamed: D7.2 (A), SW7.2
unnamed: D8.2 (A), SW8.2
unnamed: D9.2 (A), SW9.2
unnamed: D10.2 (A), SW10.2
unnamed: D11.2 (A), SW11.2
unnamed: D12.2 (A), SW12.2
unnamed: D13.2 (A), SW13.2
unnamed: D14.2 (A), SW14.2
unnamed: D15.2 (A), SW15.2
unnamed: D16.2 (A), SW16.2
unnamed: D17.2 (A), SW17.2
unnamed: D18.2 (A), SW18.2
unnamed: D19.2 (A), SW19.2
unnamed: D20.2 (A), SW20.2
unnamed: D21.2 (A), SW21.2
unnamed: D22.2 (A), SW22.2
unnamed: D23.2 (A), SW23.2
unnamed: D24.2 (A), SW24.2
unnamed: D25.2 (A), SW25.2
unnamed: D26.2 (A), SW26.2
unnamed: D27.2 (A), SW27.2
unnamed: D28.2 (A), SW28.2
unnamed: D29.2 (A), SW29.2
unnamed: D30.2 (A), SW30.2
unnamed: IC1001.4 (ADJ), R1002.1, R1003.1
unnamed: R1001.2, U1001.15 (LED_P)
unnamed: C1002.1, U1001.3 (VDDPIX)
SCLK: U1.3 (2), U1001.10 (SCLK)
VDD_2V: C1001.1, IC1001.5 (OUT), R1001.1, R1003.2, U1001.4 (VDD)
VDD_3.3V: R1004.1, U1.21 (3V3), U1001.5 (VDDIO)
VDD_5V: C1003.1, IC1001.1 (IN), IC1001.3 (EN), U1.23 (5V)

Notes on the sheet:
Power
Sensor

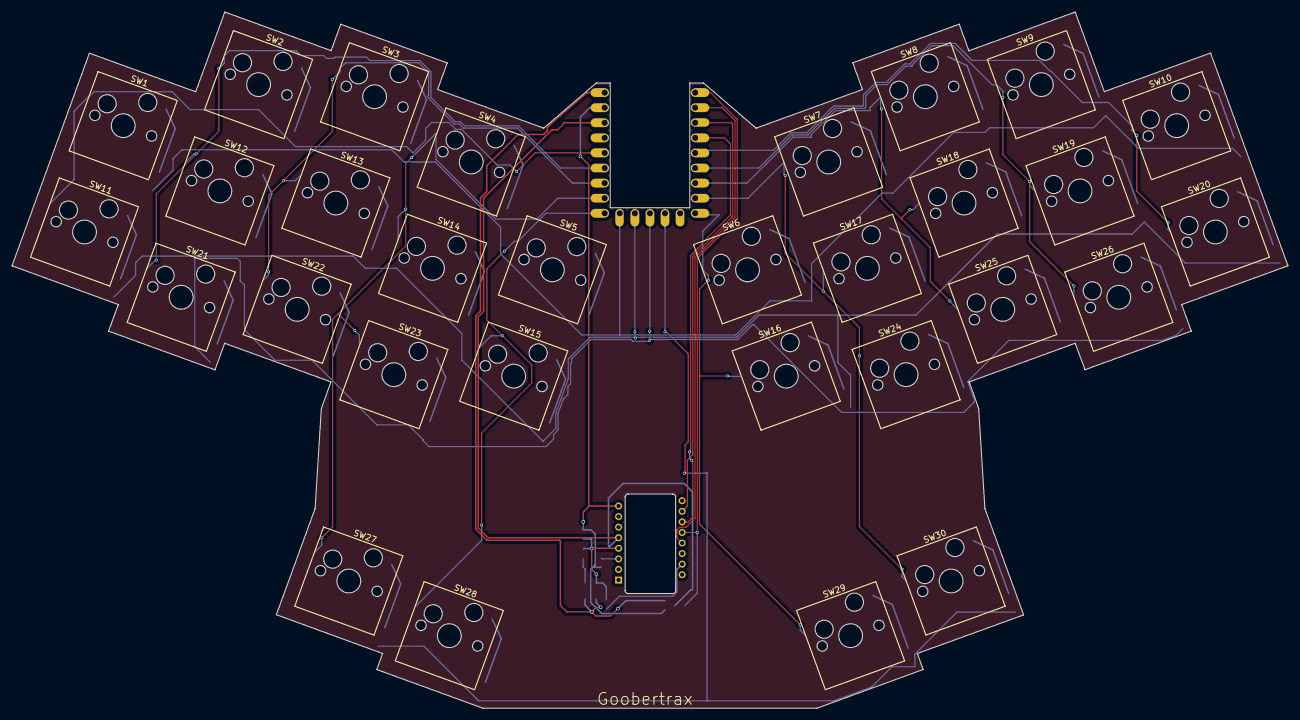
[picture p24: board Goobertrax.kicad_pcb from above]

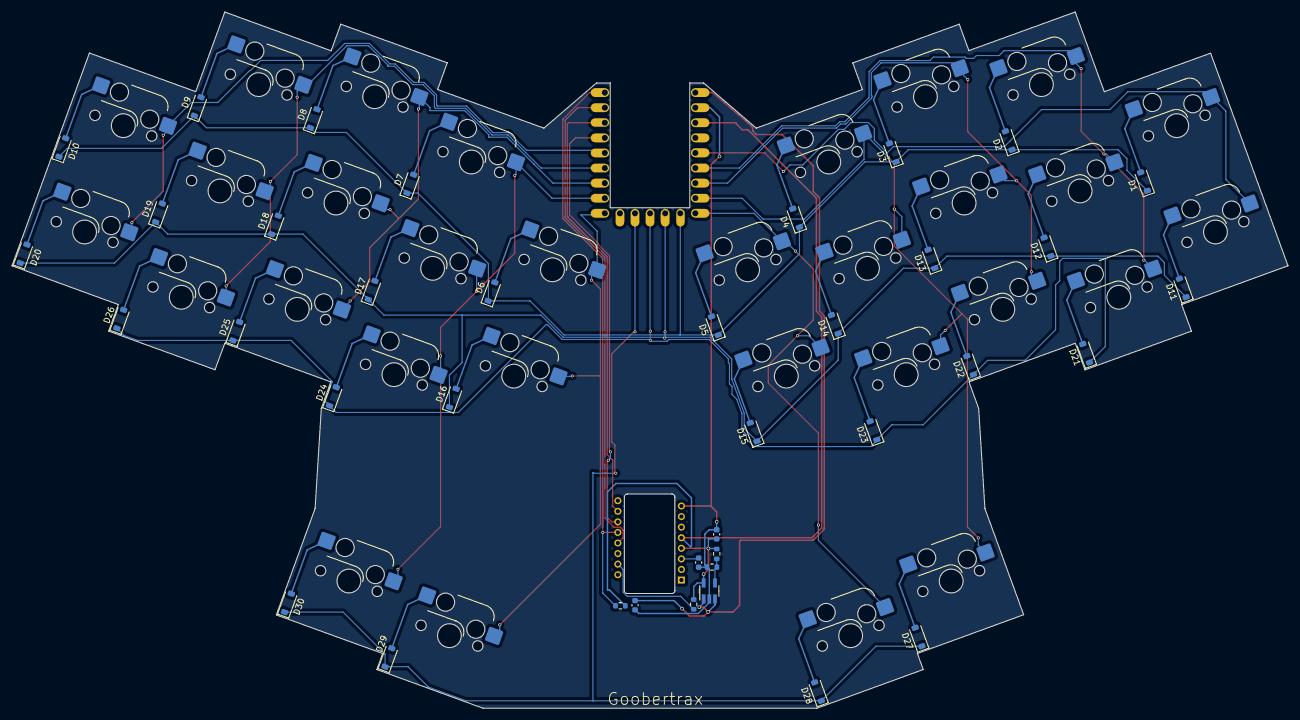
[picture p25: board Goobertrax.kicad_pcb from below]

Board: 2 copper layers, 214.8 x 117.2 mm, 70 parts (39 on the bottom side), 55 nets.

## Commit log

2024-07-26 added pcb pics
2024-08-05 Added 3d Case files.
    [case-Goober.stl, plate-goober.stl]
2024-09-03 Reorganized, Added additional boards
    Added Goobertrax, Goobertrax-e, CHore, and GooberCHOC.
    [30-B_Cu.gbl, 30-B_Mask.gbs, 30-B_Paste.gbp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]
2024-09-03 Added Goober-wi
    [Goober-wi.kicad_pcb, Goober-wi.kicad_pcb_bom.csv, Goober-wi.kicad_pcb_positions.csv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]
2024-09-03 Fixed hardware to prevent ghosting.
    [CHore.kicad_pcb, CHore.kicad_pcb_bom.csv, CHore.kicad_pcb_positions.csv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]

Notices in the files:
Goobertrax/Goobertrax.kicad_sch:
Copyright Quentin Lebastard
